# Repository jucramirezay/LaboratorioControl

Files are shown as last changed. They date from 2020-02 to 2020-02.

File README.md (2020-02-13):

# LaboratorioControl
Repositorio del laboratorio de control, contiene los códigos para el funcionamiento del laboratorio, descargar la carpeta, separar las guías y los códigos del Arduino y NodeMCU y ejecutar el archivo broker.js que se encuentra en la carpeta "servidor" con el comando "node broker.js".

El servidor contiene una serie de frameworks y paquetes en uso, sin embargo, lo mejor para el usuario es instalarlos por cuenta propia, ya que las versiones pueden variar en gran medida. 

Para instalar los paquetes basta con utilizar el comando. 

npm install nombrePaquete --save

En muchos casos es necesario el uso del super usuario (sudo) para realizar la instalación de manera correcta. La instalación se debe realizar en la carpeta raiz del servidor, es decir, la caperta donde esta ubicado el archivo broker.js. A continuación se brinda el ejemplo de como instalar los paquetes utilizados en el servidor.

sudo npm install chart.js --save \\
sudo npm install ejs --save \\
sudo npm install express --save \\
sudo npm install mosca --save \\
sudo npm install mqtt --save \\
sudo npm install socket.io --save \\

Estos paquete se instalan en una carpeta llamada node_modules, la cual se ubica en la carpeta donde se realizó la instalación. 

Se tienen los códigos del Arduino y del NodeMCU para cada experimento. 

Para la impresión del circuito, el archivo que se debe abrir en kicad (o en algún otro visor de pcb) es el denominado Tesis2.2.

Finalmente, se anexan dos guías, una para el uso del laboratorio, explicando brevemente el objetivo de cada experimento, su funcionamiento y la manera de utilizar la interfaz gráfica. La segunda guía indica como anexar un nuevo experimento, demostrando así la escalabilidad del laboratorio.

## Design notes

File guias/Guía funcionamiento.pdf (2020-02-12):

# Guía de laboratorio de control, integrado con IoT

## 1. Preliminares

### 1.1. Introduccion´

El laboratorio de control posee en funcionamiento dos experimentos, un levitador neumatico y ´ una planta virtual de nivel de agua en un tanque, los cuales pueden ser manipulados por el estudiante desde sus dispositivos moviles. El presente informe indica de que manera puede ser utilizado el ´ laboratorio por parte de los usuarios, resaltando el funcionamiento de la interfaz grafica, los datos ´ a enviar, su funcionamiento dentro de los experimentos y las partes que componen cada uno.

### 1.2. Objetivos de los experimentos

Reforzar los conceptos vistos en clase de control, teniendo en cuenta como estos pueden ser aplicados en una planta real.

Verificar de manera física como la variacion de valores como, amplitud de la referencia, ´ periodo del paso, constante proporcional, constante integral y constante derivativa, juegan un papel importante en el comportamiento de los experimentos.

Interpretar los resultados obtenidos de manera grafica y de manera visual, por medio del ´ laboratorio.

Acercar al estudiante al concepto del internet de las cosas, demostrando su utilidad y puesta en marcha por medio del intercambio de informacion entre el usuario y los experimentos. ´

## 2. Experimentos

### 2.1. Experimento uno

Se espera que con este experimento el estudiante obtenga la habilidad de interpretar como los
cambios (aumento o disminucion) en las constantes del PID afectan de manera instant ´ | anea la res- ´
puesta de la planta, teniendo en cuenta que la senal de control (en bits) indica la cantidad de tensi ˜ | on´
que llega hacia el ventilador por medio del PWM.
El experimento uno consta de un levitador neumatico. Este posee como m ´ | odulos constructivos ´
los siguientes elementos.

tubo acrílico 60 cm.

Soporte del tubo y del ventilador realizado en impresion 3D. ´

Base para el arduino, NodeMCU y para el soporte superior en impresion 3D. ´

Ventilador 12 Voltios y 2 Amperios.

Sensor laser (VL53L0X) ´

Arduino UNO

NodeMCU rev 3.0

Shield de Arduino con circuito de control del ventilador.

elemento levitante realizado con Legos.

En la siguiente figura se puede apreciar la planta que conforma el experimento.

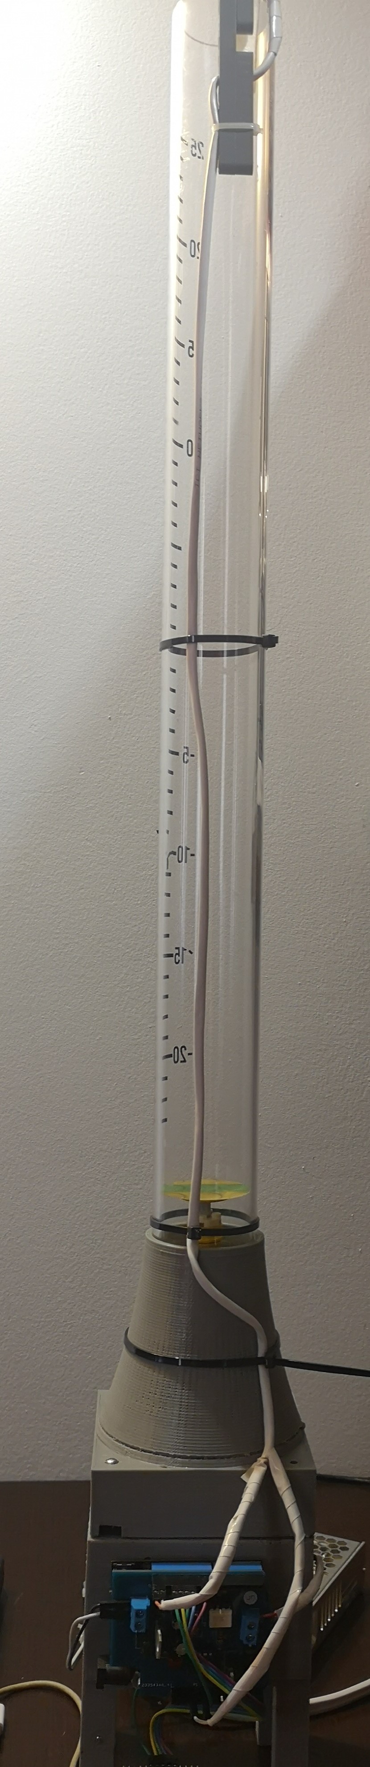
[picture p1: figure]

Figura 1: Levitador neumatico ´

El Arduino contiene un programa con el controlador PID y una salida PWM, el NodeMCU posee en su software la capacidad de enviar datos de manera inalambrica al servidor por medio del ´
protocolo MQTT y de manera alambrica al Arduino, esto ´ | ultimo por medio del protocolo SPI. ´

El programa que contiene el Arduino realiza la medicion de distancia por medio del sensor ´
laser, verificando en que posici ´ | on esta el objeto levitante. Se crea una referencia (paso) la cual ´
indica el valor al cual el objeto debe estabilizarse, en centímetros. Se ingresa a la rutina de control, donde se controla el sistema por medio de un controlador PID, el cual se utiliza para entregar el
valor de la senal de control en voltios, lista para ser utilizada en el PWM que maneja la tensi ˜ | on del ´
ventilador. En este punto es importante tener en cuenta dos cosas, la primera, el valor de la senal de ˜ control ingresa a una funcion que ’satura’ la variable, ya que el PWM funciona con valores entre ´ 0 y 1024, puede ser posible que el PID entregue un valor en bits superior a 1024 o inferior a 0, por lo cual es necesario limitar la variable, segundo, el laboratorio permite el cambio en los valores de las constantes del PID (constante proporcional, integral y derivativa) para verificar así, como un
cambio en estas cantidades afecta la senal de control y por ende, el valor de la tensi ˜ | on que llega ´

al ventilador. Para comprender de forma clara el funcionamiento explicado en el parrafo, se puede ´ observar en la siguiente imagen el lazo de control.

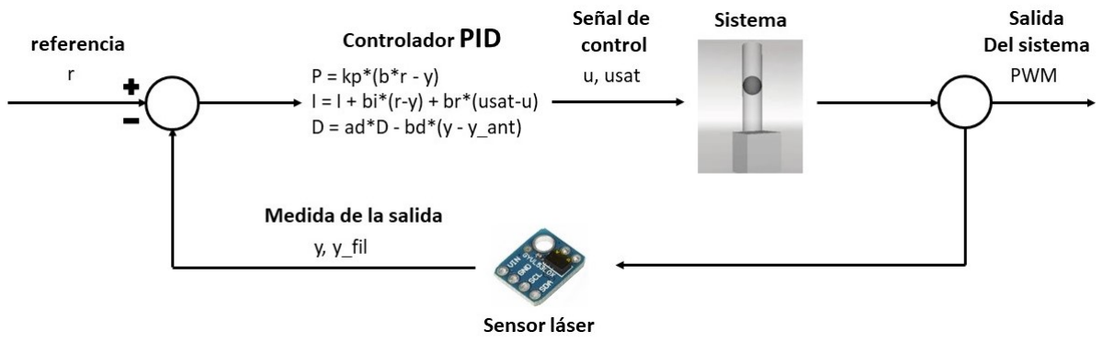
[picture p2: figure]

Figura 2: Lazo de control levitador neumatico ´

Como se indico en un principio, la comunicacion entre el arduino y el NodeMCU se hace por ´ medio del protocolo SPI, claramente el codigo que contiene el Arduino posee la rutina de comuni- ´
cacion, sin embargo, como esta es necesaria para la obtenci ´ | on de los valores que env ´ | ía el usuario
desde el navegador, se ejecuta cada cierto tiempo, para que no exista interrupcion entre la llegada ´ de los datos y la rutina de control.

La principal ventaja de este experimento se encuentra en el tiempo de respuesta, ya que la planta tiene la capacidad de mostrar instantaneamente como las variaciones de los valores enviados ´ pueden afectar el comportamiento de manera automatica, por ejemplo, al aumentar o disminuir el ´
valor de la referencia, se observa como el levitador instantaneamente env ´ | ía el objeto levitante al
punto indicado.

A modo de ejemplo, se pueden realizar el siguiente par de variaciones, e interpretar los resultados de acuerdo a los conocimientos teoricos de la asignatura. ´

Prueba uno: Mejorar la respuesta que tiene el levitador por defecto, realizando la variacion´ de las constantes así:

kp = 0.4
kd = 0.07
ki = 0.27

Prueba dos: Verificar una oscilacion en el elemento levitante, variando los valores de las ´ constantes así:

kp = No variar
kd = 0
ki = 0

Finalmente, se espera que el estudiante sepa interpretar las consecuencias de las variaciones que se realicen, así como generar y enviar nuevos valores de acuerdo al conocimiento obtenido en sistemas de control.

### 2.2. Experimento dos

Se construyo una segunda planta, sin embargo, este sistema es virtual, es decir, su construcci ´ | on´
se hace netamente de forma matematica en el c ´ | odigo programado en la placa Arduino, simulando el ´
nivel de llenado de un tanque. Al no existir modulos f ´ | ísicos no se dara incapie en la construcci ´ | on del ´
sistema. En la siguiente figura se puede apreciar el lazo de control construido para el experimento.

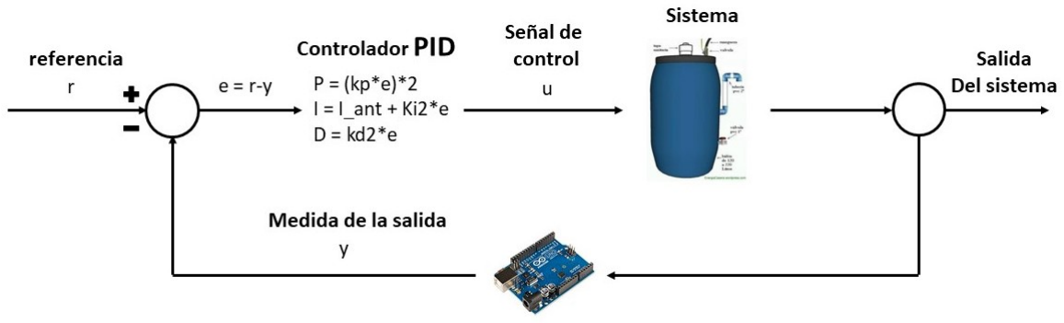
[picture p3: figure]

Figura 3: Lazo de control tanque

El codigo interno del Arduino es similar al del experimento uno, teniendo una funci ´ | on espe- ´
cifica para realizar la comunicacion SPI con el NodeMCU, as ´ | í como la rutina de control que se
ejecuta cada cierto tiempo por medio de interrupciones software. La principal diferencia radica en la construccion del controlador PID (como se puede apreciar en la figura 2 y 3, los valores P, I y ´ D son diferentes). Así mismo, el valor de la referencia no es positivo y negativo, para este caso es positivo y cero.
Finalmente, se pueden realizar variaciones de las constantes proporcional, integral y derivativa para este experimento. A modo de ejemplo, se puede mejorar la respuesta del sistema con los siguientes valores.

kp = 3
ki = 1.4
kd = 1.6

## 3. Uso del servidor

El usuario puede interactuar con los experimentos desde cualquier dispositivo que tenga cone-
xion a internet. Para poder realizar la conexi ´ | on al servidor, es necesario utilizar un navegador como ´
chrome, mozilla o edge (internet explorer y el navegador propio de algunos dispositivos moviles ´ pueden tener problemas de compatibilidad). Para poder realizar la conexion basta con escribir en el ´
espacio de direccionamiento de paginas la direcci ´ | on IP del dispositivo que se este utilizando como ´
servidor en ese momento, en cuyo caso para el Raspberry Pi es 192.168.4.1:3000

Una vez se ingresa al laboratorio, se presenta una pagina de bienvenida, como en la siguiente ´ imagen.

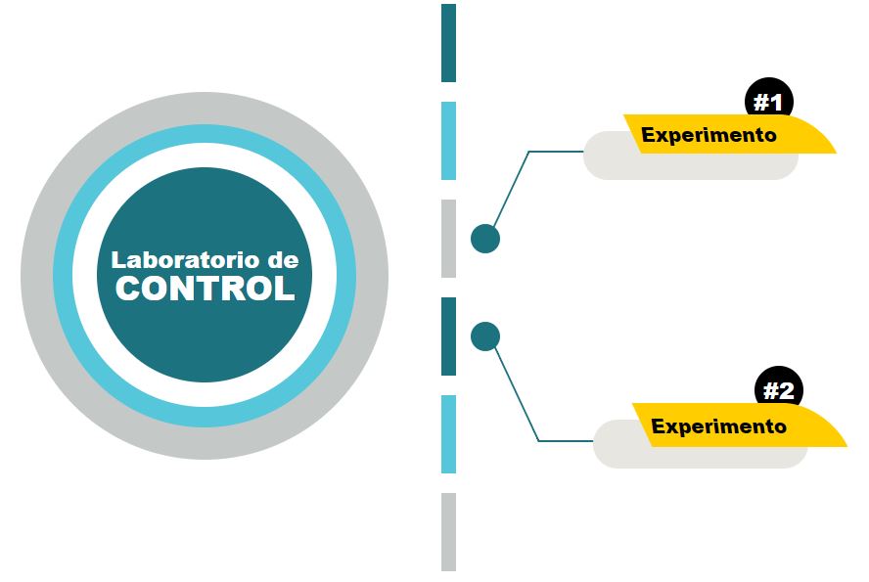
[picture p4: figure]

Figura 4: Pagina bienvenida laboratorio ´

Allí se puede escoger cualquiera de los dos experimentos. Cuando el usuario hace la seleccion, ´
el servidor envía un dato de confirmacion al NodeMCU del experimento, indic ´ | andole que puede ´
empezar con el envio de datos por medio del protocolo MQTT. Esto se hace con el fin de evitar ´
una comunicacion en doble v ´ | ía, es decir, para evitar que ambos experimentos envíen datos al tiem-
po y exista conflicto en las graficas generadas. De acuerdo a lo anterior, si un usuario selecciona ´
el experimento uno, el boton respectivo al experimento dos se bloquear ´ | a. Para que vuelva a estar ´
disponible, es necesario que todos los clientes salgan del experimento uno.

Una vez se ingresa al experimento, se puede apreciar la siguiente interfaz.

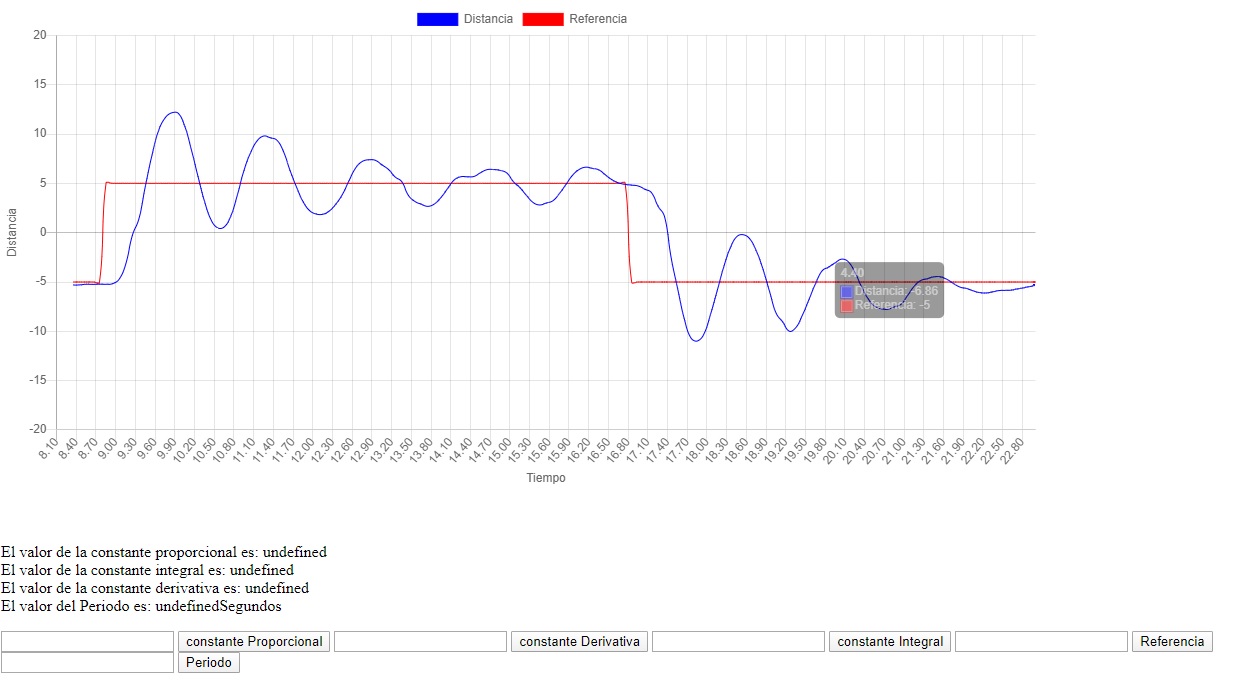
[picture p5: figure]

Figura 5: Pagina primer experimento ´

Para ambos experimentos la interfaz posee las mismas funciones, el unico cambio que se tiene ´ es en los títulos de los datos graficados y el titulo de la grafica. ´

La interfaz es bastante intuitiva, en la parte superior se tiene un boton denominado ’volver al ´
home’ que permite volver a la pagina principal (selecci ´ | on de experimentos). Seguido de este se ´
observan los ejes que permiten visualizar la grafica generada cuando el experimento esta en uso, ´
en la parte superior de dicha grafica se observan dos rect ´ | angulos de color rojo y azul que indi- ´
can el color que posee cada elemento que se visualiza a la hora de mostrar los datos. El eje x se toma como el eje del tiempo, a medida que el experimento avanza, el eje se va moviendo hacia la izquierda, mostrando los resultados en un rango especifico, cada division tiene 300 milisegundos. ´
Finalmente en la parte inferior estan los botones y las casillas que permiten la interacci ´ | on por ´
parte del usuario con los experimentos. Se tienen 5 casillas, así como 5 botones, cada uno perteneciente a la casilla dispuesta inmediatamente a la izquierda. De acuerdo al boton presionado, se ´
envía el dato que el usuario ingreso. Se pueden ingresar n ´ | umeros de punto flotante, no se permiten ´
caracteres como letras ni tampoco palabras completas, el numero se debe ingresar con la notaci ´ | on´
de punto, ejemplo, 4.5; tampoco es posible ingresar un valor inferior a 1 sin el cero que le antecede a la izquierda, es decir, se debe ingresar 0.5, por dar un ejemplo. A continuacion se indica cada ´ casilla y su respectivo dato a enviar, de izquierda a derecha.

Constante Proporcional: El valor enviado por este medio se guarda en el Arduino en la variable kp, necesaria para los calculos de la parte proporcional del PID. Se puede enviar un ´ valor de punto flotante, consecuente con los rangos de valores para la constante proporcional.

Constante Derivativa: El valor enviado por este medio se guarda en el Arduino en la variable kd, necesaria para los calculos de la parte derivativa del PID. Se puede enviar un valor de ´ punto flotante, consecuente con los rangos de valores para la constante derivativa.

Constante Integral: El valor enviado por este medio se guarda en el Arduino en la variable ki, necesaria para los calculos de la parte integral del PID. Se puede enviar un valor de punto ´ flotante, consecuente con los rangos de valores para la constante integral.

Referencia: Este valor esta limitado por la planta física, por ejemplo, para el levitador indica la cantidad de cm a la cual se desea llegar desde el cero de referencia, es recomendable no exceder los 20 cm. ya que el objeto levitante puede llegar a estar posicionado muy cerca al
sensor laser y esto significa que no habr ´ | a lectura. Se puede enviar un valor de punto flotante. ´

Periodo: El periodo indica el tiempo que tendra la onda cuadrada tanto para el valor positivo ´ como para el negativo (haciendo el símil con una onda normal, en este caso el usuario estaría indicando la mitad del periodo, no el periodo completo). El valor que el cliente envía, el Arduino lo interpreta como la cantidad de segundos que ha de tener la onda cuadrada, por ello es importante limitar este valor a solamente una cifra decimal. Para el primer experimento se debe enviar el valor en segundos, para el segundo experimento, este debe ser indicado en milisegundos (4 segundos = 4000 milisegundos).

Como el servidor del laboratorio permite la comunicacion por medio de WebSockets, el paso de ´ datos se hace en tiempo real, una vez el usuario envía la informacion, esta llega de forma inmediata ´ al servidor y se envía directamente al Arduino.

## 4. Informacion extra ´

Para consultar informacion extra, se puede referir al repositorio en GIT del laboratorio, donde ´
se encuentra otra guía de explicacion y los c ´ | odigos utilizados. ´

https://github.com/jucramirezay/LaboratorioControl

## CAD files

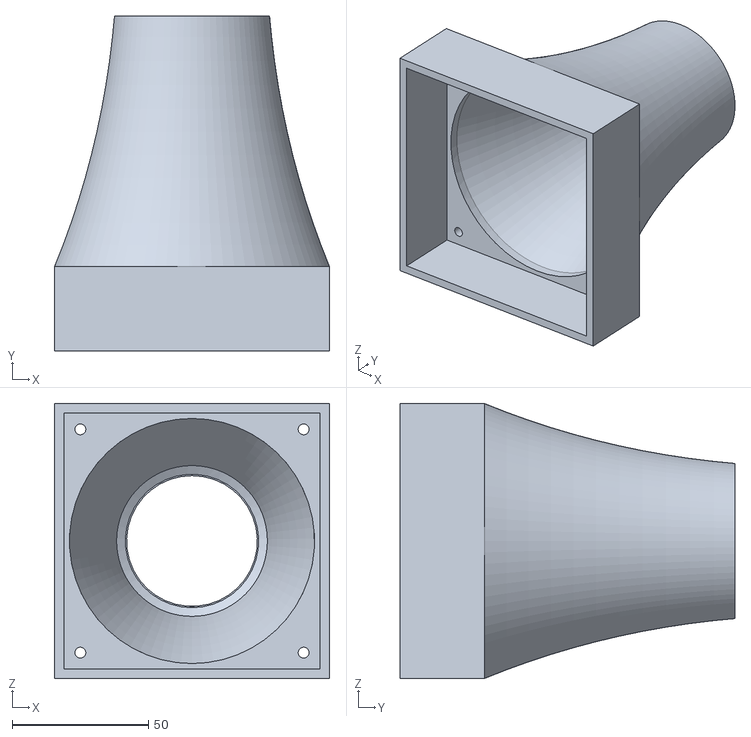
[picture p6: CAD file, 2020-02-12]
Impresion3D/Pieza juan Camilo 4.STL
101.0 x 123.0 x 101.0

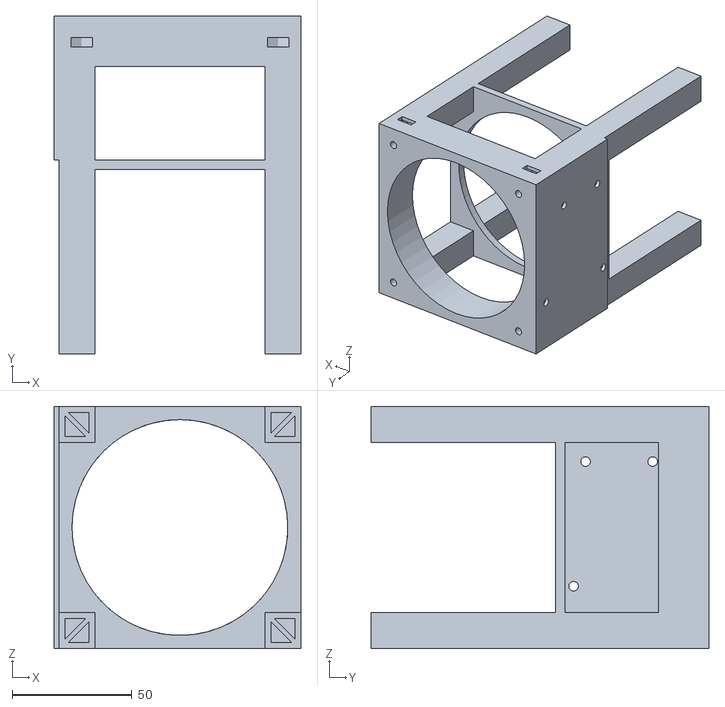
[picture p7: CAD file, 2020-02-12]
Impresion3D/Base Juan Camilo.STL
103.0 x 141.0 x 101.0

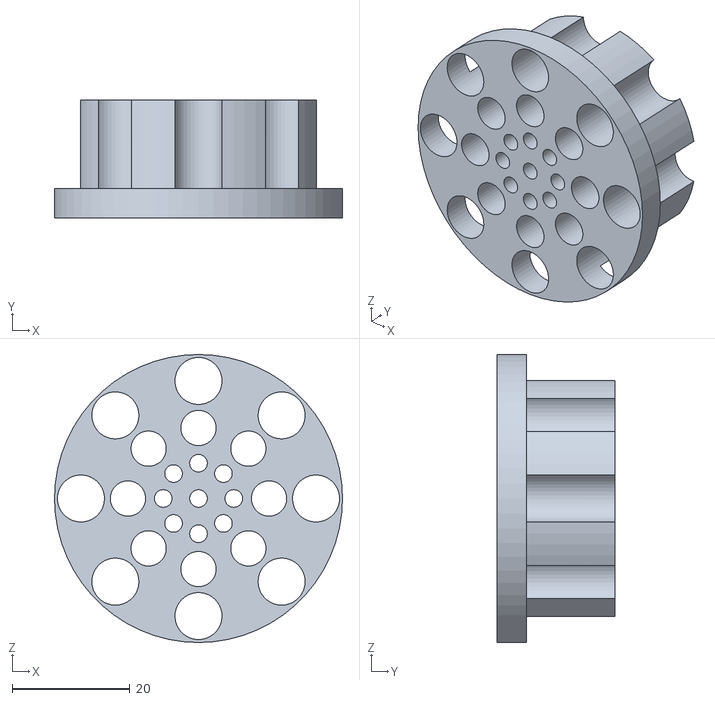
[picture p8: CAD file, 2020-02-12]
Impresion3D/Concentrador Juan Camilo.STL
49.0 x 20.0 x 49.0

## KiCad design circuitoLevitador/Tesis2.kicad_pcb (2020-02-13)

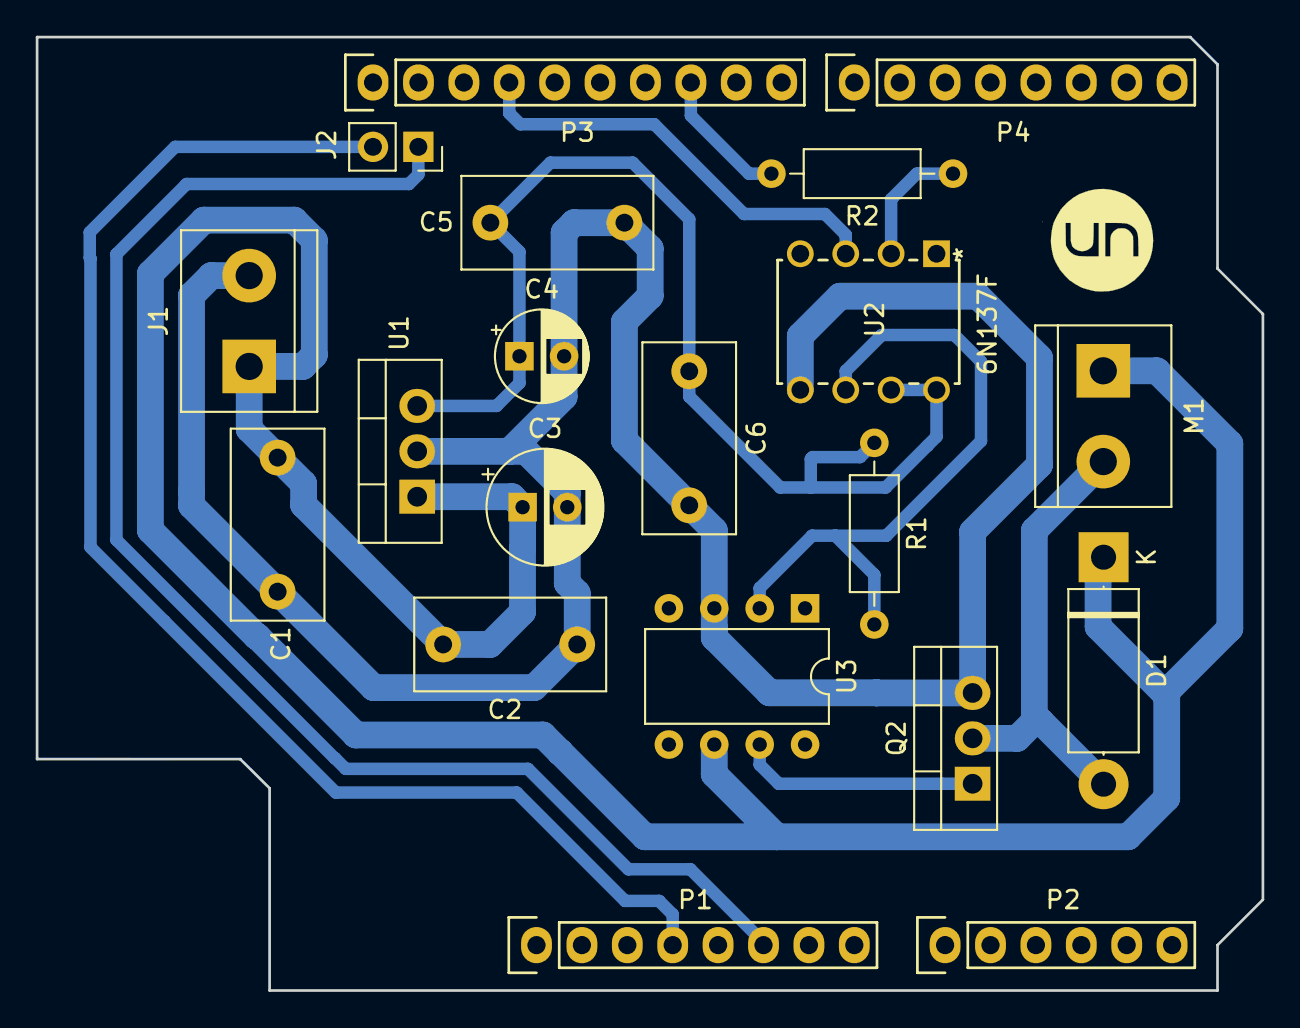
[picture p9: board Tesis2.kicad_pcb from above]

Board: 2 copper layers, 68.6 x 53.3 mm, 20 parts (0 on the bottom side), 11 nets.

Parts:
C1: 47nF; C_Disc_D10.5mm_W5.0mm_P7.50mm
C2: 470nF; C_Disc_D10.5mm_W5.0mm_P7.50mm
C3: 470uF; CP_Radial_D6.3mm_P2.50mm
C4: 100uF; CP_Radial_D5.0mm_P2.50mm
C5: 100nF; C_Disc_D10.5mm_W5.0mm_P7.50mm
C6: 10nF; C_Disc_D10.5mm_W5.0mm_P7.50mm
D1: D; D_5W_P12.70mm_Horizontal
J1: Fuente; TerminalBlock_bornier-2_P5.08mm
J2: ASensor2; PinSocket_1x02_P2.54mm_Vertical
M1: Fan; TerminalBlock_bornier-2_P5.08mm
P1: Power; Socket_Strip_Arduino_1x08
P2: Analog; Socket_Strip_Arduino_1x06
P3: Digital; Socket_Strip_Arduino_1x10
P4: Digital; Socket_Strip_Arduino_1x08
Q2: IRF630; TO-220-3_Vertical
R1, R2: 220; R_Axial_DIN0207_L6.3mm_D2.5mm_P10.16mm_Horizontal
U1: L7805; TO-220-3_Vertical
U2: 6N137F
U3: MC33152; DIP-8_W7.62mm

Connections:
+3V3: J2.2, P1.4
+12V: C1.1, C2.1, C3.1, D1.1, J1.1, M1.1, U1.1, U3.6
/10(**/SS): P3.8, R2.2
GNDPWR: C1.2, C2.2, C3.2, C4.2, C5.2, C6.2, J1.2, Q2.3, U1.2, U2.5, U3.3
unnamed: C4.1, C5.1, C6.1, R1.1, U1.3, U2.7, U2.8
unnamed: D1.2, M1.2, Q2.2
unnamed: J2.1, P1.6
unnamed: P3.4, U2.3
unnamed: Q2.1, U3.7
unnamed: R1.2, U2.6, U3.2
unnamed: R2.1, U2.2

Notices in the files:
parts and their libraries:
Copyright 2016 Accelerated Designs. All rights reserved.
